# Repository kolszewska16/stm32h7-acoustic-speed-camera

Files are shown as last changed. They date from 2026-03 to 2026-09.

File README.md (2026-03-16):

# stm32h7-acoustic-speed-camera
Real-time acoustic event logger on STM32H723ZG. Hardware-accelerated PDM acquisition and CMSIS-DSP analysis. Features automatic event triggering with SD card logging and camera integration.

### Overview
This project is a system for monitoring and analyzing traffic noise in real-time. It doesn't just measure decibels — it "understands" the frequency spectrum and takes action. When a noise threshold is violated, the system triggers a camera and logs the event data (photo) to an SD card.

### Tech Stack & Key Features
* **MCU:** STM32H723ZG (Cortex-M7)
* **Audio:** Digital PDM MEMS microphones via **DFSDM**
* **OS:** **FreeRTOS** for multitasking
* **Storage:** **SDMMC + FatFs** for high-speed event logging

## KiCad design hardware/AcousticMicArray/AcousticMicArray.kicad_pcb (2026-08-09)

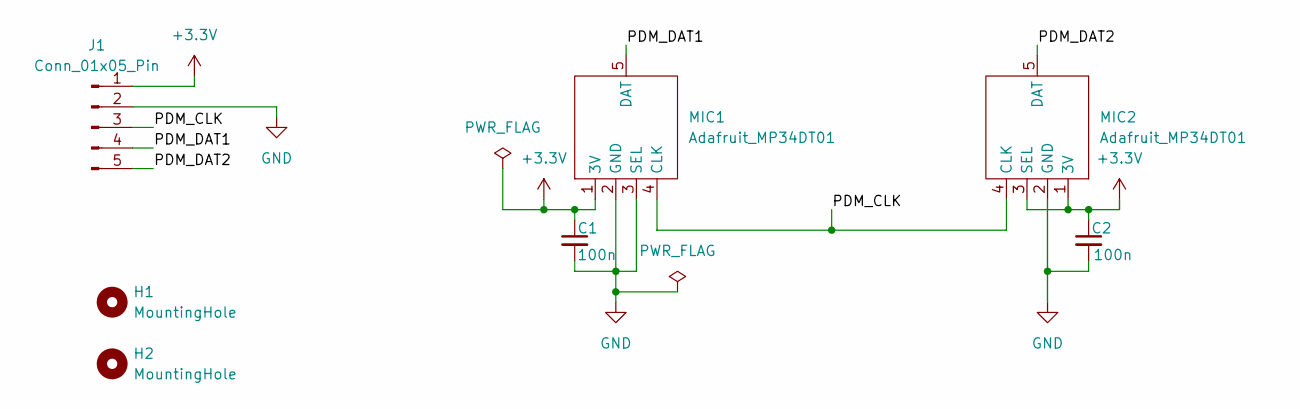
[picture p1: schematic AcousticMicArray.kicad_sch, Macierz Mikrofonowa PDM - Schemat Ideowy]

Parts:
C1, C2: 100n; C_0805_2012Metric_Pad1.18x1.45mm_HandSolder
H1, H2: MountingHole; MountingHole_3.2mm_M3
J1: Conn_01x05_Pin; PinHeader_1x05_P2.54mm_Vertical
MIC1, MIC2: Adafruit_MP34DT01; PinSocket_1x05_P2.54mm_Vertical

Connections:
+3.3V: C1.1, C2.1, J1.1, MIC1.1 (3V), MIC2.1 (3V), MIC2.3 (SEL)
/PDM_CLK: J1.3, MIC1.4 (CLK), MIC2.4 (CLK)
/PDM_DAT1: J1.4, MIC1.5 (DAT)
/PDM_DAT2: J1.5, MIC2.5 (DAT)
GND: C1.2, C2.2, J1.2, MIC1.2 (GND), MIC1.3 (SEL), MIC2.2 (GND)

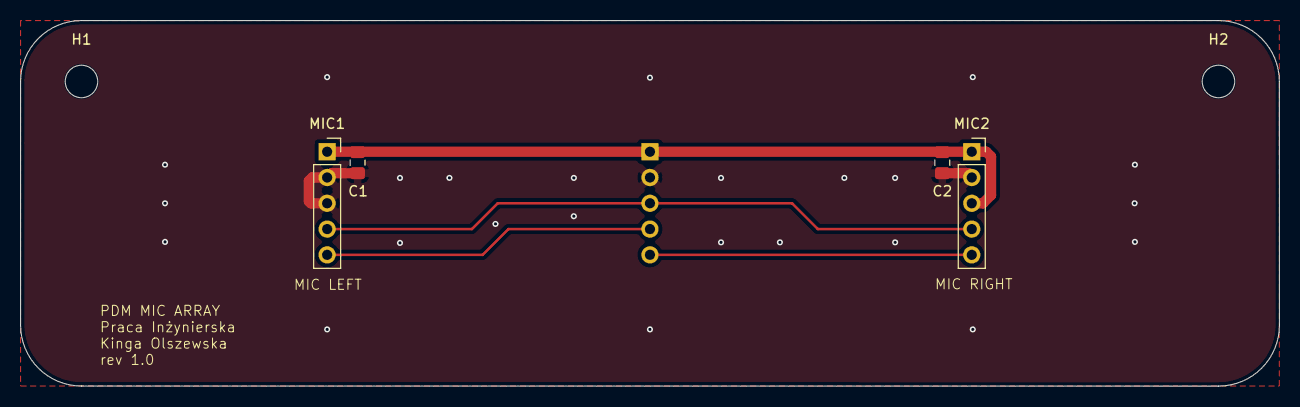
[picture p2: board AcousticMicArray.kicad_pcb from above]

Board: 2 copper layers, 124.0 x 36.0 mm, 7 parts (1 on the bottom side), 5 nets.

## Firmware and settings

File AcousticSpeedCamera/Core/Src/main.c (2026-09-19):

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
/* Includes ------------------------------------------------------------------*/
#include "main.h"
#include "cmsis_os.h"
#include "dcmi.h"
#include "dfsdm.h"
#include "dma.h"
#include "i2c.h"
#include "spi.h"
#include "gpio.h"

/* USER CODE BEGIN Includes */
#include "audio_processor.h"
#include "ili9341.h"
#include "lvgl.h"

/* USER CODE END Includes */


COM_InitTypeDef BspCOMInit;

/* USER CODE BEGIN PV */
extern ILI9341_HandleTypeDef lcd;
extern volatile lv_display_t *active_disp;
extern osThreadId_t audioTaskHandle;

/* USER CODE END PV */

void SystemClock_Config(void);
static void MPU_Config(void);
void MX_FREERTOS_Init(void);
/* USER CODE BEGIN 0 */
void HAL_DFSDM_FilterRegConvHalfCpltCallback(DFSDM_Filter_HandleTypeDef *hdfsdm) {
	if(hdfsdm == &hdfsdm1_filter0) {
		osThreadFlagsSet(audioTaskHandle, 0x01);
	}

	if(hdfsdm == &hdfsdm1_filter1) {
		osThreadFlagsSet(audioTaskHandle, 0x01);
	}
}

void HAL_DFSDM_FilterRegConvCpltCallback(DFSDM_Filter_HandleTypeDef *hdfsdm) {
	if(hdfsdm == &hdfsdm1_filter0) {
		osThreadFlagsSet(audioTaskHandle, 0x02);
	}

	if(hdfsdm == &hdfsdm1_filter1) {
		osThreadFlagsSet(audioTaskHandle, 0x02);
	}
}

void HAL_SPI_TxCpltCallback(SPI_HandleTypeDef *hspi) {
	if(hspi->Instance == SPI3) {
		HAL_GPIO_WritePin(lcd.cs_port, lcd.cs_pin, GPIO_PIN_SET);

		if(active_disp != NULL) {
			lv_display_flush_ready((lv_display_t*)active_disp);
		}
	}
}

/* USER CODE END 0 */

/**
  * @brief  The application entry point.
  * @retval int
  */
int main(void)
{

  /* MPU Configuration--------------------------------------------------------*/
  MPU_Config();

  /* MCU Configuration--------------------------------------------------------*/

  /* Reset of all peripherals, Initializes the Flash interface and the Systick. */
  HAL_Init();

  /* Configure the system clock */
  SystemClock_Config();

  /* Initialize all configured peripherals */
  MX_GPIO_Init();
  MX_DMA_Init();
  MX_DFSDM1_Init();
  MX_SPI3_Init();
  MX_DCMI_Init();
  MX_I2C1_Init();
  /* Init scheduler */
  osKernelInitialize();  /* Call init function for freertos objects (in cmsis_os2.c) */
  MX_FREERTOS_Init();

  /* Initialize COM1 port (115200, 8 bits (7-bit data + 1 stop bit), no parity */
  BspCOMInit.BaudRate   = 115200;
  BspCOMInit.WordLength = COM_WORDLENGTH_8B;
  BspCOMInit.StopBits   = COM_STOPBITS_1;
  BspCOMInit.Parity     = COM_PARITY_NONE;
  BspCOMInit.HwFlowCtl  = COM_HWCONTROL_NONE;
  if (BSP_COM_Init(COM1, &BspCOMInit) != BSP_ERROR_NONE)
  {
    Error_Handler();
  }

  /* Start scheduler */
  osKernelStart();

  /* We should never get here as control is now taken by the scheduler */

  /* Infinite loop */
  /* USER CODE BEGIN WHILE */
  while (1)
  {

    /* USER CODE END WHILE */

    /* USER CODE BEGIN 3 */
  }
  /* USER CODE END 3 */
}

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
 /* MPU Configuration */

void MPU_Config(void)
{
  MPU_Region_InitTypeDef MPU_InitStruct = {0};

  /* Disables the MPU */
  HAL_MPU_Disable();

  /** Initializes and configures the Region and the memory to be protected
  */
  MPU_InitStruct.Enable = MPU_REGION_ENABLE;
  MPU_InitStruct.Number = MPU_REGION_NUMBER0;
  MPU_InitStruct.BaseAddress = 0x0;
  MPU_InitStruct.Size = MPU_REGION_SIZE_4GB;
  MPU_InitStruct.SubRegionDisable = 0x87;
  MPU_InitStruct.TypeExtField = MPU_TEX_LEVEL0;
  MPU_InitStruct.AccessPermission = MPU_REGION_NO_ACCESS;
  MPU_InitStruct.DisableExec = MPU_INSTRUCTION_ACCESS_DISABLE;
  MPU_InitStruct.IsShareable = MPU_ACCESS_SHAREABLE;
  MPU_InitStruct.IsCacheable = MPU_ACCESS_NOT_CACHEABLE;
  MPU_InitStruct.IsBufferable = MPU_ACCESS_NOT_BUFFERABLE;

  HAL_MPU_ConfigRegion(&MPU_InitStruct);

  /** Initializes and configures the Region and the memory to be protected
  */
  MPU_InitStruct.Number = MPU_REGION_NUMBER1;
  MPU_InitStruct.BaseAddress = 0x24000000;
  MPU_InitStruct.Size = MPU_REGION_SIZE_256KB;
  MPU_InitStruct.SubRegionDisable = 0x0;
  MPU_InitStruct.TypeExtField = MPU_TEX_LEVEL1;
  MPU_InitStruct.AccessPermission = MPU_REGION_FULL_ACCESS;

  HAL_MPU_ConfigRegion(&MPU_InitStruct);
  /* Enables the MPU */
  HAL_MPU_Enable(MPU_PRIVILEGED_DEFAULT);

}

/**
  * @brief  Period elapsed callback in non blocking mode
  * @note   This function is called  when TIM6 interrupt took place, inside
  * HAL_TIM_IRQHandler(). It makes a direct call to HAL_IncTick() to increment
  * a global variable "uwTick" used as application time base.
  * @param  htim : TIM handle
  * @retval None
  */
void HAL_TIM_PeriodElapsedCallback(TIM_HandleTypeDef *htim)
{
  if (htim->Instance == TIM6)
  {
    HAL_IncTick();
  }
}

/**
  * @brief  This function is executed in case of error occurrence.
  * @retval None
  */
void Error_Handler(void)
{
  /* USER CODE BEGIN Error_Handler_Debug */
  /* User can add his own implementation to report the HAL error return state */
  __disable_irq();
  while (1)
  {
  }
  /* USER CODE END Error_Handler_Debug */
}
#ifdef USE_FULL_ASSERT
/**
  * @brief  Reports the name of the source file and the source line number
  *         where the assert_param error has occurred.
  * @param  file: pointer to the source file name
  * @param  line: assert_param error line source number
  * @retval None
  */
void assert_failed(uint8_t *file, uint32_t line)
{
  /* USER CODE BEGIN 6 */
  /* User can add his own implementation to report the file name and line number,
     ex: printf("Wrong parameters value: file %s on line %d\r\n", file, line) */
  /* USER CODE END 6 */
}
#endif /* USE_FULL_ASSERT */

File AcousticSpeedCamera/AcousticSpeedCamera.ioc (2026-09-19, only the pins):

Mcu.UserName=STM32H723ZGTx
PA13(JTMS/SWDIO).GPIO_Label=SWDIO
PA13(JTMS/SWDIO).Signal=DEBUG_JTMS-SWDIO
PA14(JTCK/SWCLK).GPIO_Label=SWCLK
PA14(JTCK/SWCLK).Signal=DEBUG_JTCK-SWCLK
PA4.Signal=DCMI_HSYNC
PA6.Signal=DCMI_PIXCLK
PA8.Signal=RCC_MCO_1
PB0.Signal=S_CKOUTDFSDM1
PB1.Signal=S_DATAIN1DFSDM1
PB13.Signal=DCMI_D2
PB14.Signal=GPIO_Output
PB6.Signal=I2C1_SCL
PB7.Signal=I2C1_SDA
PB9.Signal=DCMI_D7
PC10.Signal=SPI3_SCK
PC11.GPIO_Label=LCD_BL
PC11.Signal=GPIO_Output
PC12.Signal=SPI3_MOSI
PC14-OSC32_IN.Signal=RCC_OSC32_IN
PC15-OSC32_OUT.Signal=RCC_OSC32_OUT
PC6.Signal=DCMI_D0
PC7.Signal=DCMI_D1
PC8.GPIO_Label=LCD_DC
PC8.Signal=GPIO_Output
PC9.Signal=DCMI_D3
PD2.GPIO_Label=LCD_CS
PD2.Signal=GPIO_Output
PD3.Signal=DCMI_D5
PD7.Signal=S_DATAIN4DFSDM1
PD8.Signal=USART3_TX
PD9.Signal=USART3_RX
PE1.GPIO_Label=LCD_RST
PE1.Signal=GPIO_Output
PE4.Signal=DCMI_D4
PE5.Signal=DCMI_D6
PG4.GPIO_Label=CAM_RST
PG4.Signal=GPIO_Output
PG5.GPIO_Label=CAM_PWDN
PG5.Signal=GPIO_Output
PG9.Signal=DCMI_VSYNC
PH0-OSC_IN.Signal=RCC_OSC_IN

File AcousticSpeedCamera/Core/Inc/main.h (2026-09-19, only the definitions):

#define CAM_RST_Pin GPIO_PIN_4
#define CAM_RST_GPIO_Port GPIOG
#define CAM_PWDN_Pin GPIO_PIN_5
#define CAM_PWDN_GPIO_Port GPIOG
#define LCD_DC_Pin GPIO_PIN_8
#define LCD_DC_GPIO_Port GPIOC
#define SWDIO_Pin GPIO_PIN_13
#define SWDIO_GPIO_Port GPIOA
#define SWCLK_Pin GPIO_PIN_14
#define SWCLK_GPIO_Port GPIOA
#define LCD_BL_Pin GPIO_PIN_11
#define LCD_BL_GPIO_Port GPIOC
#define LCD_CS_Pin GPIO_PIN_2
#define LCD_CS_GPIO_Port GPIOD
#define LCD_RST_Pin GPIO_PIN_1
#define LCD_RST_GPIO_Port GPIOE

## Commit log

2026-06-20 add dBA calibration based on microphone datasheet
2026-07-19 normalize DFSDM data and calibrate dBA levels
2026-08-09 add AcousticMicArray PCB project and custom template
    [AcousticMicArray.kicad_pcb, AcousticMicArray.kicad_sch]
2026-08-10 add ILI9341 driver and implementation test task
2026-08-14 add DMA-based SPI flush for ILI9341 + LVGL
2026-09-14 add DCMI peripheral configuration for camera module
2026-09-14 add STMicroelectronics OV5640 driver files
2026-09-18 add OV5640 BSP, DCMI and high-level camera API layers
2026-09-18 add FreeRTOS task for camera init/capture smoke test
2026-09-19 validate camera init and capture test task
2026-09-19 improve camera init/capture reliability and RTOS synchronization
2026-09-19 add initial v1.0 schematic (outdated pinout)
    [AcousticSpeedCameraShield.kicad_pcb, AcousticSpeedCameraShield.kicad_sch, camera.kicad_sch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]
2026-09-23 update MCU pin assignments
    [AcousticSpeedCameraShield.kicad_sch, camera.kicad_sch, display.kicad_sch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]

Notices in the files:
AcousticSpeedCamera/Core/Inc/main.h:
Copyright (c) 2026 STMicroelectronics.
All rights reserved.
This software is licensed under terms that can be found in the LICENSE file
